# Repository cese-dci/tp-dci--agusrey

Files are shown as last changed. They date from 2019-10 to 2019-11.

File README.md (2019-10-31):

 Poncho PLC para CIAA7 - Agustín Rey

## Esquemático y PCB

Este repositorio contiene el los diagramas esquematicos y diseño de PCB del poncho PLC para la nueva placa CIAA7

### Estado Actual
Esquemático Terminado - Ruteo terminado - BOM Terminado
###
NOTA: El solapamiento de los bornes en el PCB es a propósito, porque asi pueden usarse
bornes de distinto número de polos a gusto del usuario.

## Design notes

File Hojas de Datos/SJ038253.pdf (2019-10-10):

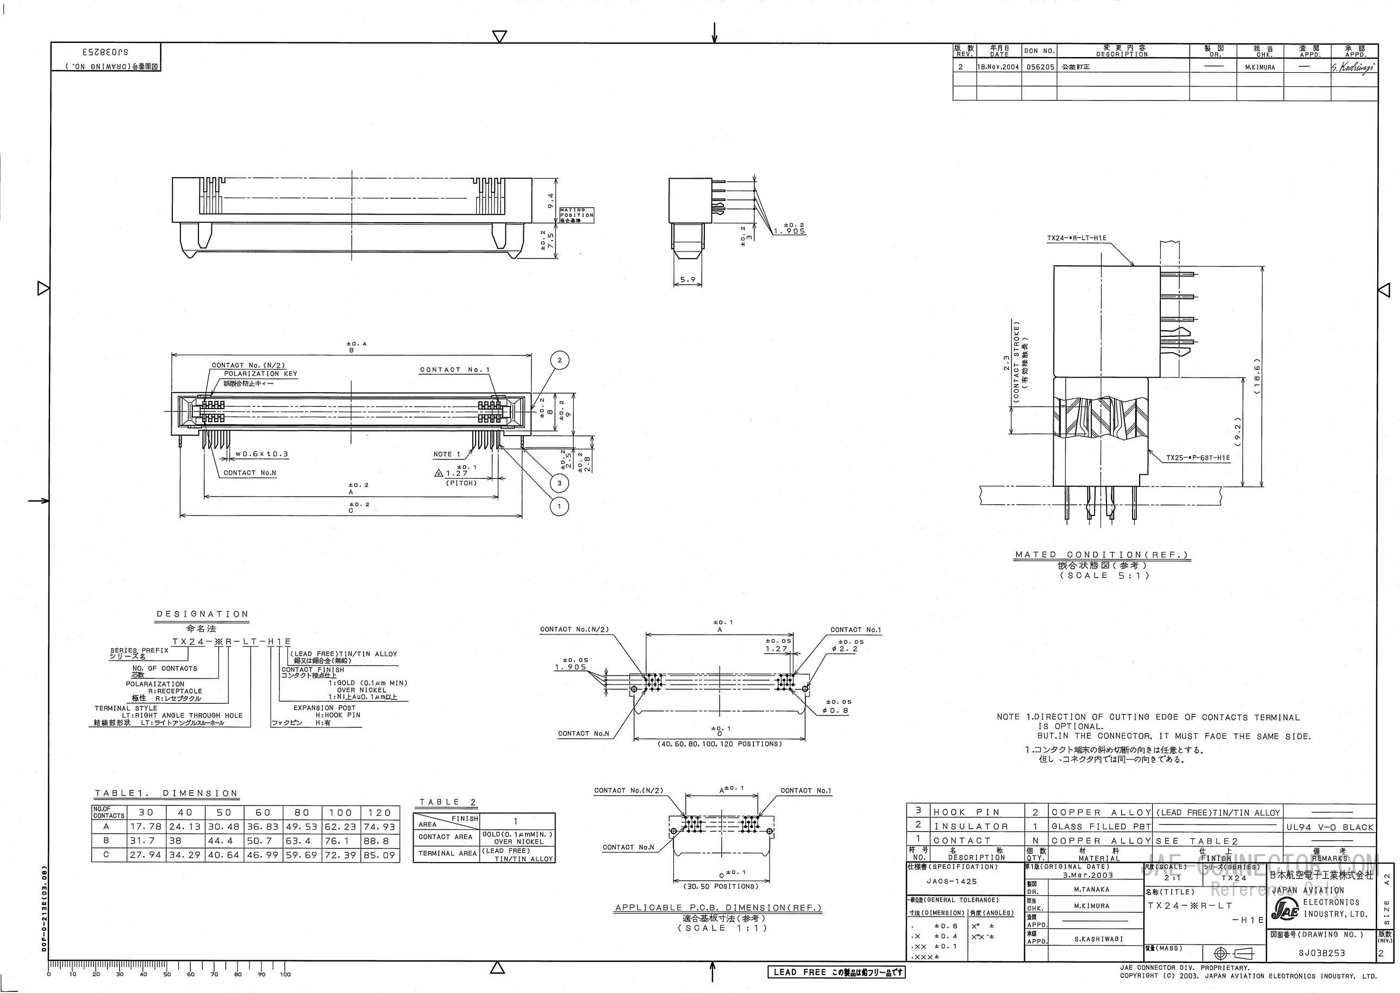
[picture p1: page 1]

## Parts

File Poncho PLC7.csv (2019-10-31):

Id | Designator | Package | Quantity | Designation | Supplier and ref
1 | J10,J7,J9 | PinSocket_2x12_P2.54mm_Vertical | 3 | Conn_02x12_Odd_Even
2 | FID3,FID2,FID1 | Fiducial_0.5mm_Mask1mm | 3 | Fiducial
3 | H8,H7,H6,H5,H1,H2,H4,H3 | MountingHole_3.2mm_M3_Pad_Via | 8 | MountingHole
4 | D8,D7,D6,D5,D4,D3,D2,D1 | LED_0805_2012Metric | 8 | LED red
5 | J18,J13 | PinSocket_2x05_P2.54mm_Vertical | 2 | Conn_02x05_Odd_Even
6 | C1,C3,C4,C9,C2 | C_0805_2012Metric | 5 | 100nF
7 | C5,C6,C7,C8 | C_1206_3216Metric | 4 | 1uF
8 | JP1,JP2,JP3,JP4 | PinHeader_1x02_P2.54mm_Vertical | 4 | Jumper
9 | Q1,Q2,Q3,Q4 | SOT-223 | 4 | FQT13N06L
10 | R1,R2,R3,R4 | R_0805_2012Metric | 4 | 100K
11 | R5,R6,R7,R8,R9,R10,R11,R12,R13,R14,R15,R16 | R_0805_2012Metric | 12 | 330
12 | R17,R19,R21,R23,R25,R27,R29,R31 | R_0805_2012Metric | 8 | 6.2K
13 | R18,R20,R22,R24,R26,R28,R30,R32 | R_0805_2012Metric | 8 | 2.7K
14 | TH1,TH2,TH3,TH4 | R_1206_3216Metric | 4 | PTS12066V100
15 | U1,U2,U3,U4 | SOT-23-5 | 4 | MCP1416
16 | U5,U6,U7,U8 | SMDIP-6_W9.53mm | 4 | VO14642AABTR
17 | U9 | QSOP-20_3.9x8.7mm_P0.635mm | 1 | SI8380P-IU
18 | J2 | TerminalBlock_WECO_120-M-311_1x03_P5.00mm_Plug-in_PCB | 1 | TB_1X3-PonchoPLC-rescue
19 | J1 | TerminalBlock_WECO_120-M-311_1x02_P5.00mm_Plug-in_PCB | 1 | TB_1X2-PonchoPLC-rescue
20 | JE3,JE2,JE1,J6,J5,J4,J3 | TerminalBlock_WECO_120-M-311_1x02_P5.00mm_Plug-in_PCB | 7 | TB_1X2
21 | JE4 | TerminalBlock_WECO_120-M-311_1x03_P5.00mm_Plug-in_PCB | 1 | TB_1X3
22 |  | OSHW-Logo2_7.3x6mm_Copper | 1
23 |  | Logo_Poncho | 1
24 | J8 | TX24-40R-LT-H1E | 1 | Conn_02x20_Counter_Clockwise

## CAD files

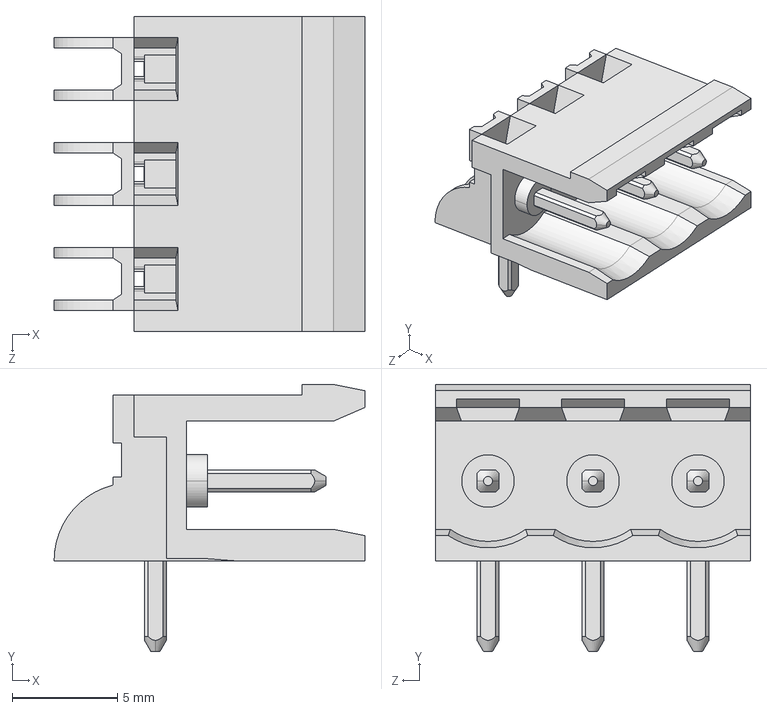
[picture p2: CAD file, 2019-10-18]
footprints/120-M-311-03.STEP
14.8 x 12.7 x 15.0 mm

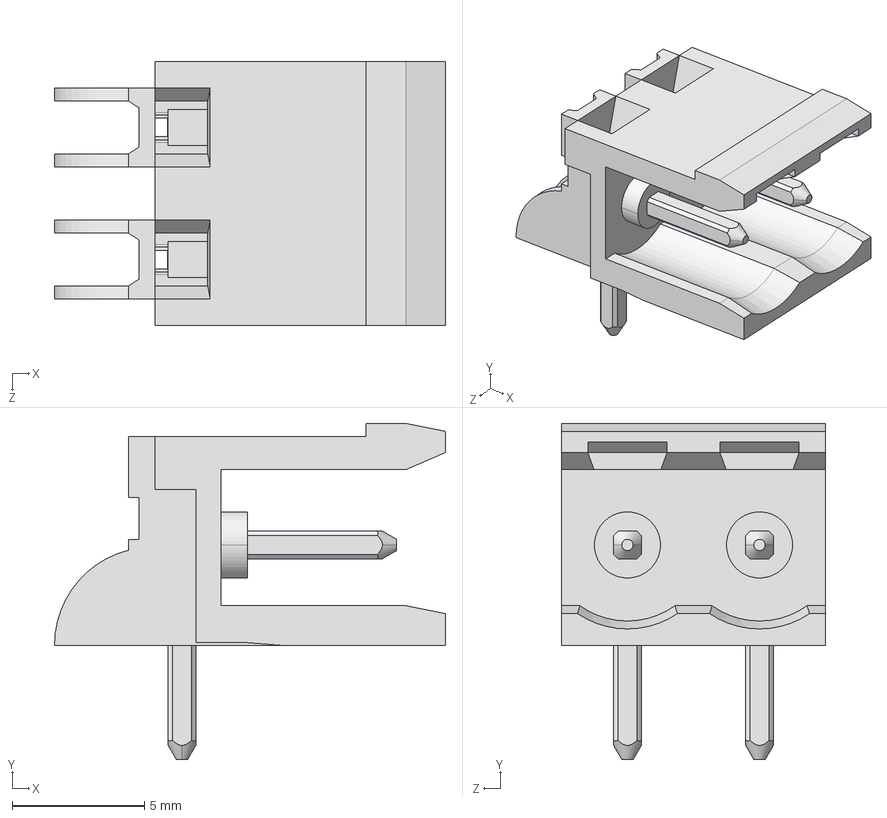
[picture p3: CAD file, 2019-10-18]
footprints/120-M-311-02.STEP
14.8 x 12.7 x 10.0 mm

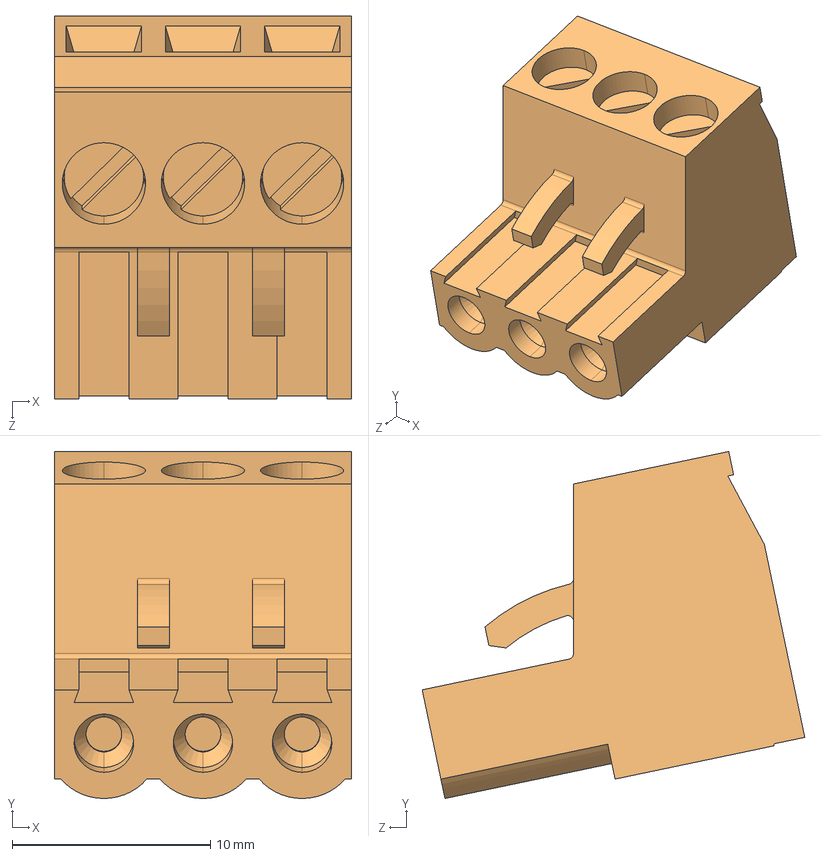
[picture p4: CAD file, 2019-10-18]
footprints/120-A-111-03.STEP
15.0 x 17.5 x 19.3 mm

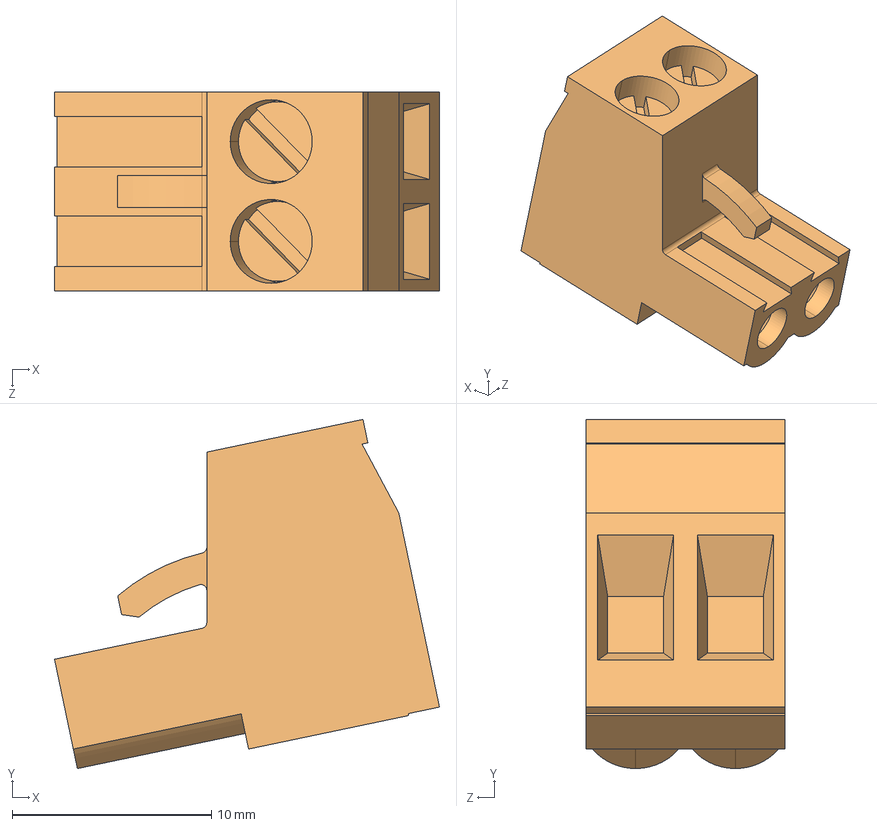
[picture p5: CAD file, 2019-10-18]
footprints/120-A-111-02.STEP
19.3 x 17.5 x 10.0 mm

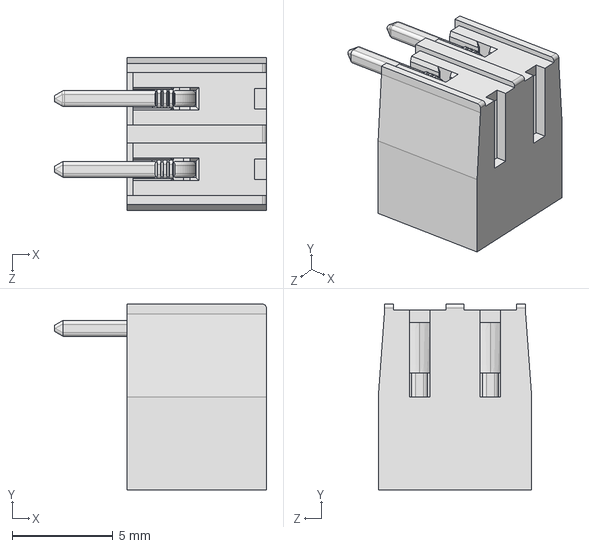
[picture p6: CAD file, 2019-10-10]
footprints/110-M-111-02.STEP
10.5 x 9.20 x 7.60 mm

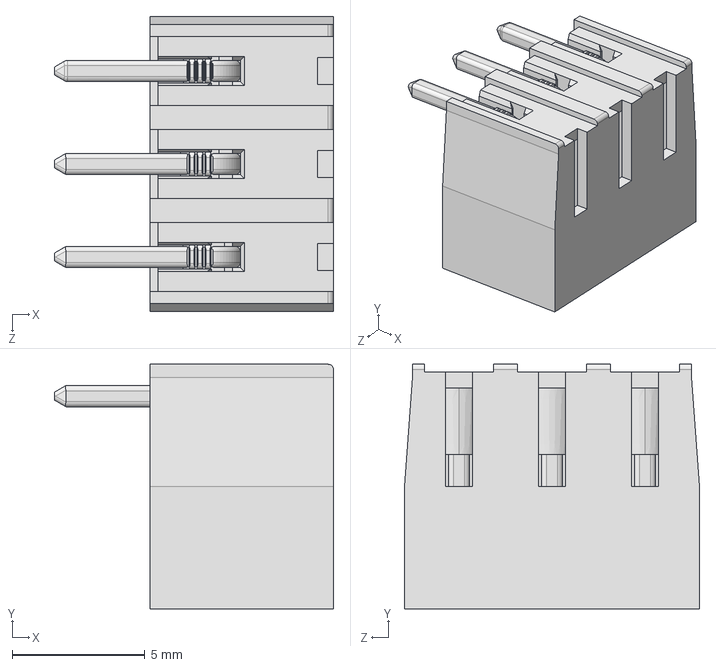
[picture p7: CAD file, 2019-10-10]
footprints/110-M-111-03.STEP
10.5 x 9.20 x 11.1 mm

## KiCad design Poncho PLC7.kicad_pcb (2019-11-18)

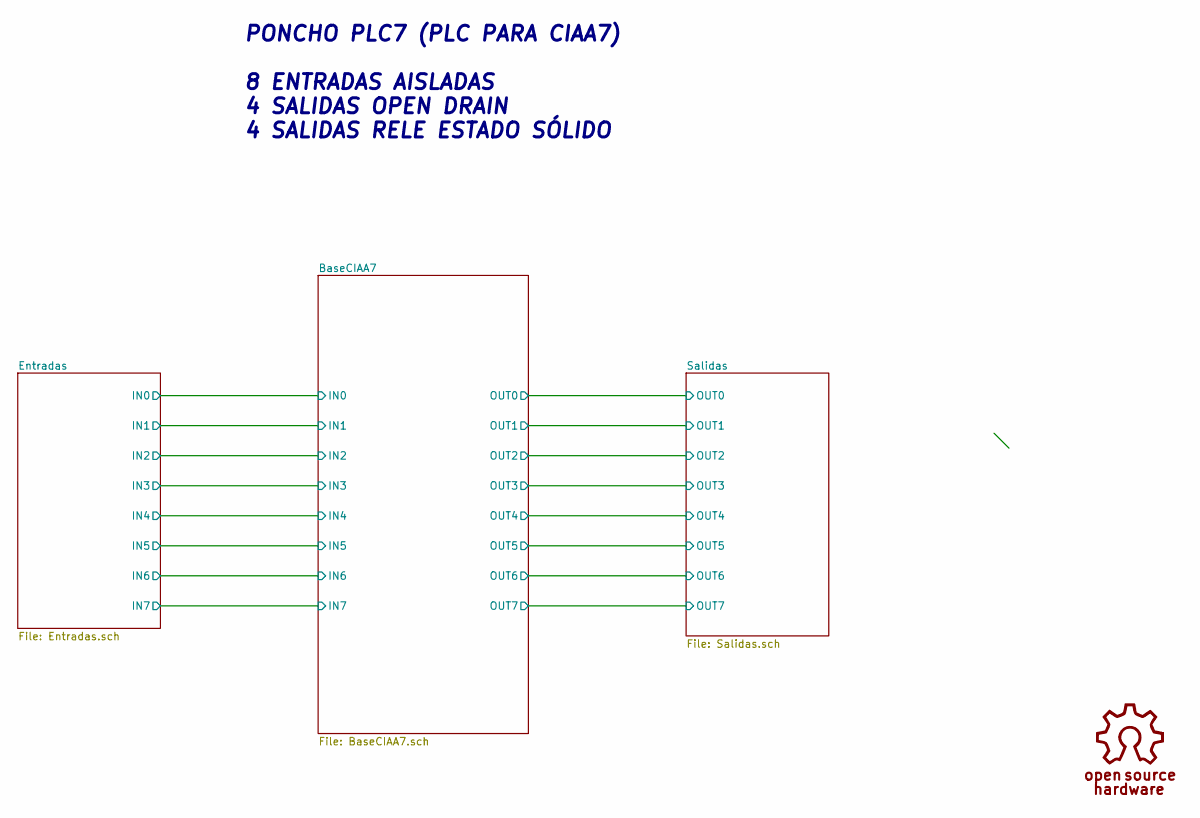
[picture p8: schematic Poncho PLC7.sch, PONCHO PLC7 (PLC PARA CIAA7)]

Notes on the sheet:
PONCHO PLC7 (PLC PARA CIAA7) 8 ENTRADAS AISLADAS 4 SALIDAS OPEN DRAIN 4 SALIDAS RELE ESTADO SÓLIDO

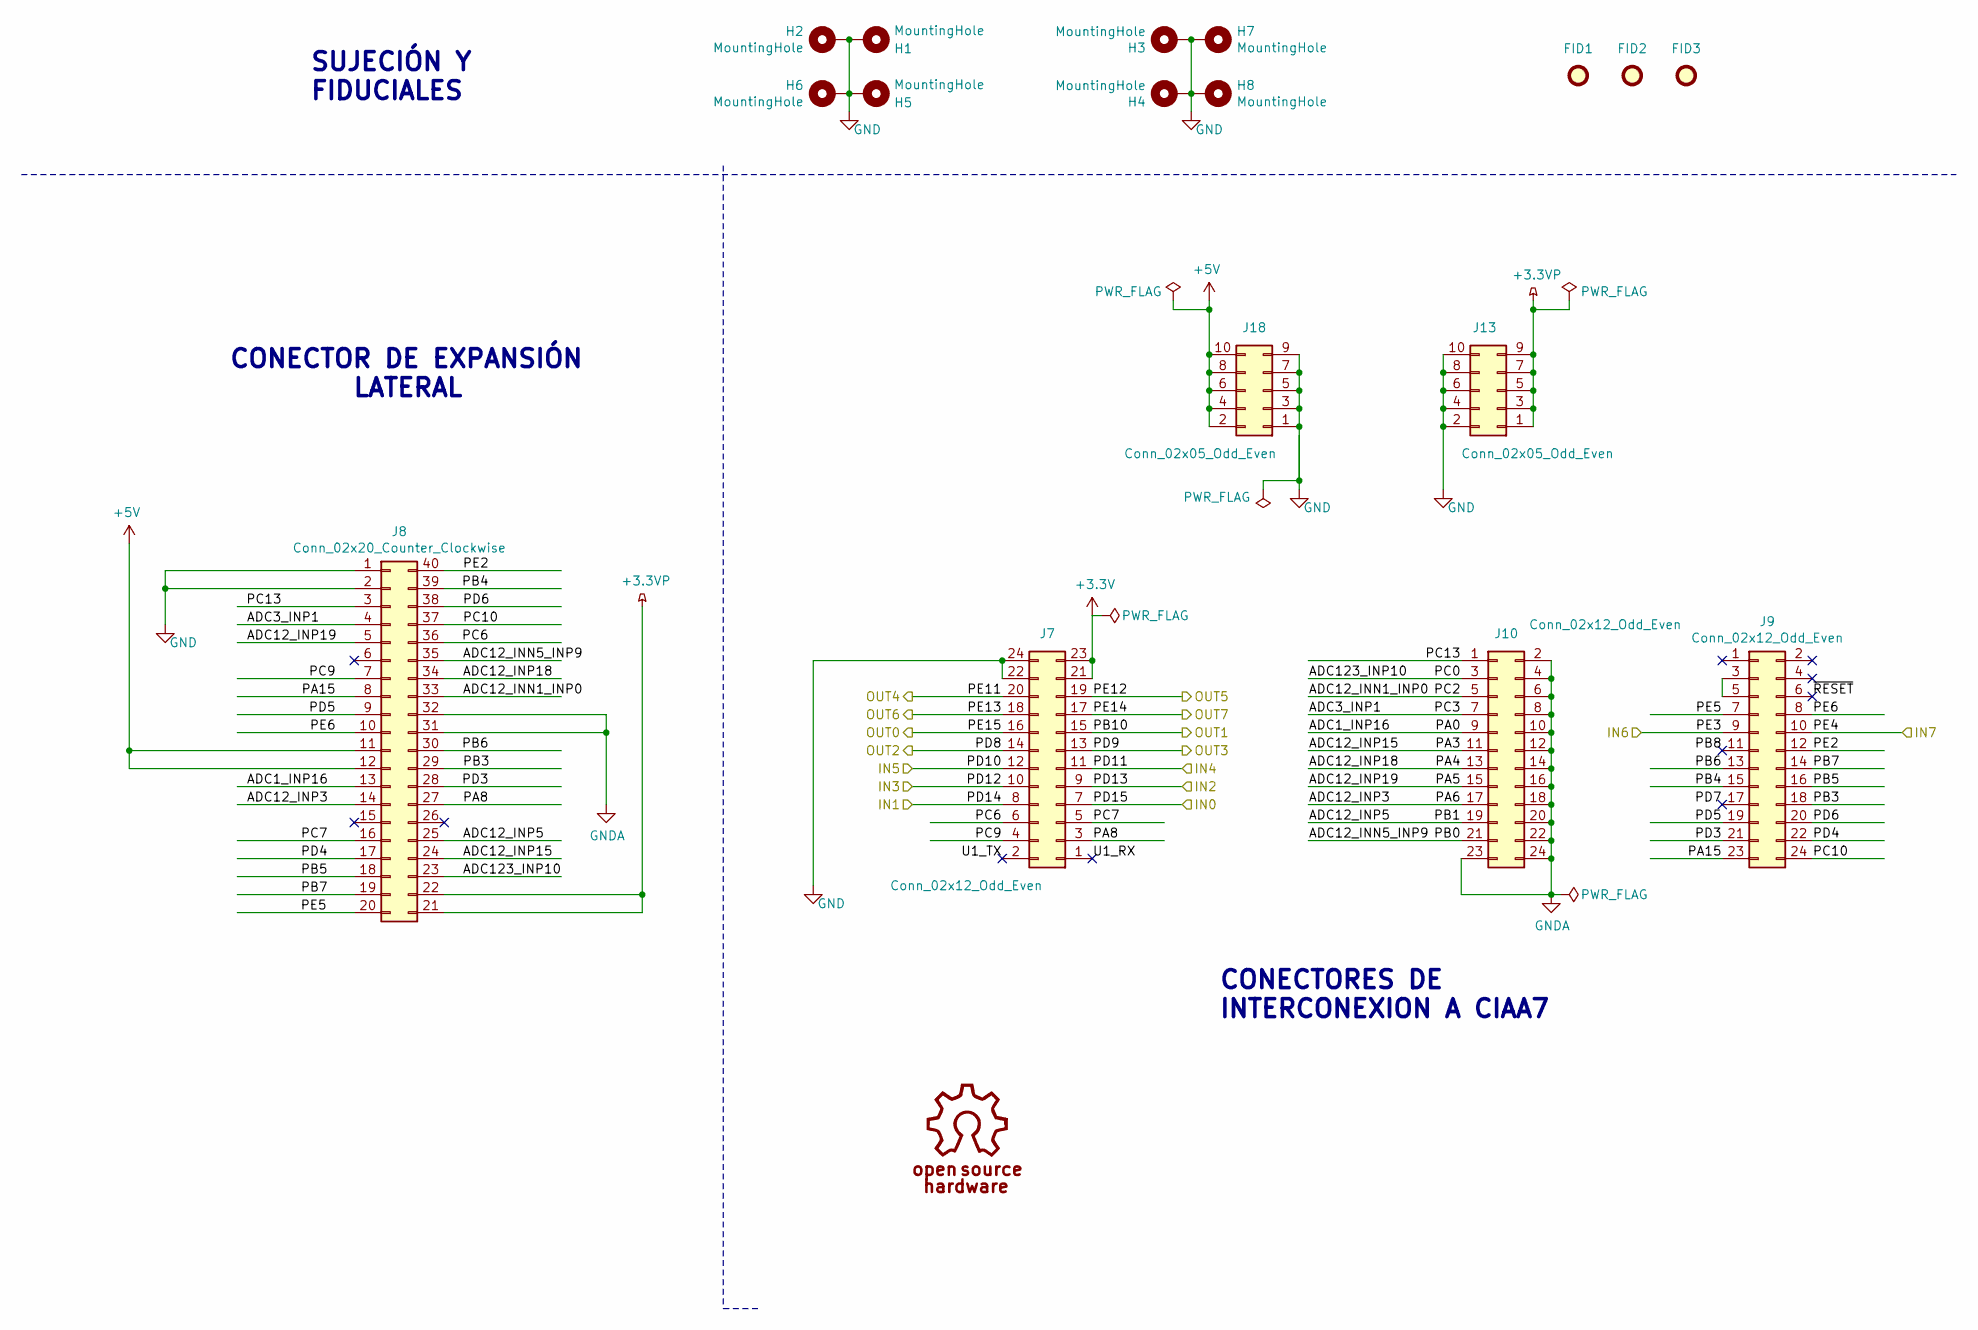
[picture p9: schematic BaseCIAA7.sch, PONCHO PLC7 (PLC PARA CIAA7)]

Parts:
FID1, FID2, FID3: Fiducial; Fiducial_0.5mm_Mask1mm
H1, H2, H3, H4, H5, H6, H7, H8: MountingHole; MountingHole_3.2mm_M3_Pad_Via
J7, J9, J10: Conn_02x12_Odd_Even; PinSocket_2x12_P2.54mm_Vertical; Digikey# 2057-PH2-12-UA-ND
J8: Conn_02x20_Counter_Clockwise; TX24-40R-LT-H1E; Digikey# 670-1386-ND
J13, J18: Conn_02x05_Odd_Even; PinSocket_2x05_P2.54mm_Vertical; Digikey# 2057-PH2-12-UA-ND

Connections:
+3.3VP: J8.21, J8.22, J13.1, J13.3, J13.5, J13.7, J13.9
+3V3: J7.21, J7.23; also elsewhere on the board
+5V: J8.11, J8.12, J18.2, J18.4, J18.6, J18.8, J18.10; also elsewhere on the board
/BaseCIAA7/ADC1_INP16: J8.13, J10.9
/BaseCIAA7/ADC3_INP1: J8.4, J10.7
/BaseCIAA7/ADC12_INN1_INP0: J8.33, J10.5
/BaseCIAA7/ADC12_INN5_INP9: J8.35, J10.21
/BaseCIAA7/ADC12_INP3: J8.14, J10.17
/BaseCIAA7/ADC12_INP5: J8.25, J10.19
/BaseCIAA7/ADC12_INP15: J8.24, J10.11
/BaseCIAA7/ADC12_INP18: J8.34, J10.13
/BaseCIAA7/ADC12_INP19: J8.5, J10.15
/BaseCIAA7/ADC123_INP10: J8.23, J10.3
/BaseCIAA7/IN0: J7.7; also elsewhere on the board
/BaseCIAA7/IN1: J7.8; also elsewhere on the board
/BaseCIAA7/IN2: J7.9; also elsewhere on the board
/BaseCIAA7/IN3: J7.10; also elsewhere on the board
/BaseCIAA7/IN4: J7.11; also elsewhere on the board
/BaseCIAA7/IN5: J7.12; also elsewhere on the board
/BaseCIAA7/IN6: J9.9; also elsewhere on the board
/BaseCIAA7/IN7: J9.10; also elsewhere on the board
/BaseCIAA7/OUT0: J7.16; also elsewhere on the board
/BaseCIAA7/OUT1: J7.15; also elsewhere on the board
/BaseCIAA7/OUT2: J7.14; also elsewhere on the board
/BaseCIAA7/OUT3: J7.13; also elsewhere on the board
/BaseCIAA7/OUT4: J7.20; also elsewhere on the board
/BaseCIAA7/OUT5: J7.19; also elsewhere on the board
/BaseCIAA7/OUT6: J7.18; also elsewhere on the board
/BaseCIAA7/OUT7: J7.17; also elsewhere on the board
/BaseCIAA7/PA8: J7.3, J8.27
/BaseCIAA7/PA15: J8.8, J9.23
/BaseCIAA7/PB3: J8.29, J9.18
/BaseCIAA7/PB4: J8.39, J9.15
/BaseCIAA7/PB5: J8.18, J9.16
/BaseCIAA7/PB6: J8.30, J9.13
/BaseCIAA7/PB7: J8.19, J9.14
/BaseCIAA7/PB8: J9.11
/BaseCIAA7/PC6: J7.6, J8.36
/BaseCIAA7/PC7: J7.5, J8.16
/BaseCIAA7/PC9: J7.4, J8.7
/BaseCIAA7/PC10: J8.37, J9.24
/BaseCIAA7/PC13: J8.3, J10.1
/BaseCIAA7/PD3: J8.28, J9.21
/BaseCIAA7/PD4: J8.17, J9.22
/BaseCIAA7/PD5: J8.9, J9.19
/BaseCIAA7/PD6: J8.38, J9.20
/BaseCIAA7/PD7: J9.17
/BaseCIAA7/PE2: J8.40, J9.12
/BaseCIAA7/PE5: J8.20, J9.7
/BaseCIAA7/PE6: J8.10, J9.8
/BaseCIAA7/U1_RX: J7.1
/BaseCIAA7/U1_TX: J7.2
/BaseCIAA7/~RESET: J9.6
GND: H1.1, H2.1, H3.1, H4.1, H5.1, H6.1, H7.1, H8.1, J7.22, J7.24, J8.1, J8.2, J13.2, J13.4, J13.6, J13.8, J13.10, J18.1, J18.3, J18.5, J18.7, J18.9; also elsewhere on the board
GNDA: J8.31, J8.32, J10.2, J10.4, J10.6, J10.8, J10.10, J10.12, J10.14, J10.16, J10.18, J10.20, J10.22, J10.23, J10.24
unnamed: J9.3, J9.5

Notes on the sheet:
CONECTORES DE INTERCONEXION A CIAA7
CONECTOR DE EXPANSIÓN LATERAL
SUJECIÓN Y FIDUCIALES

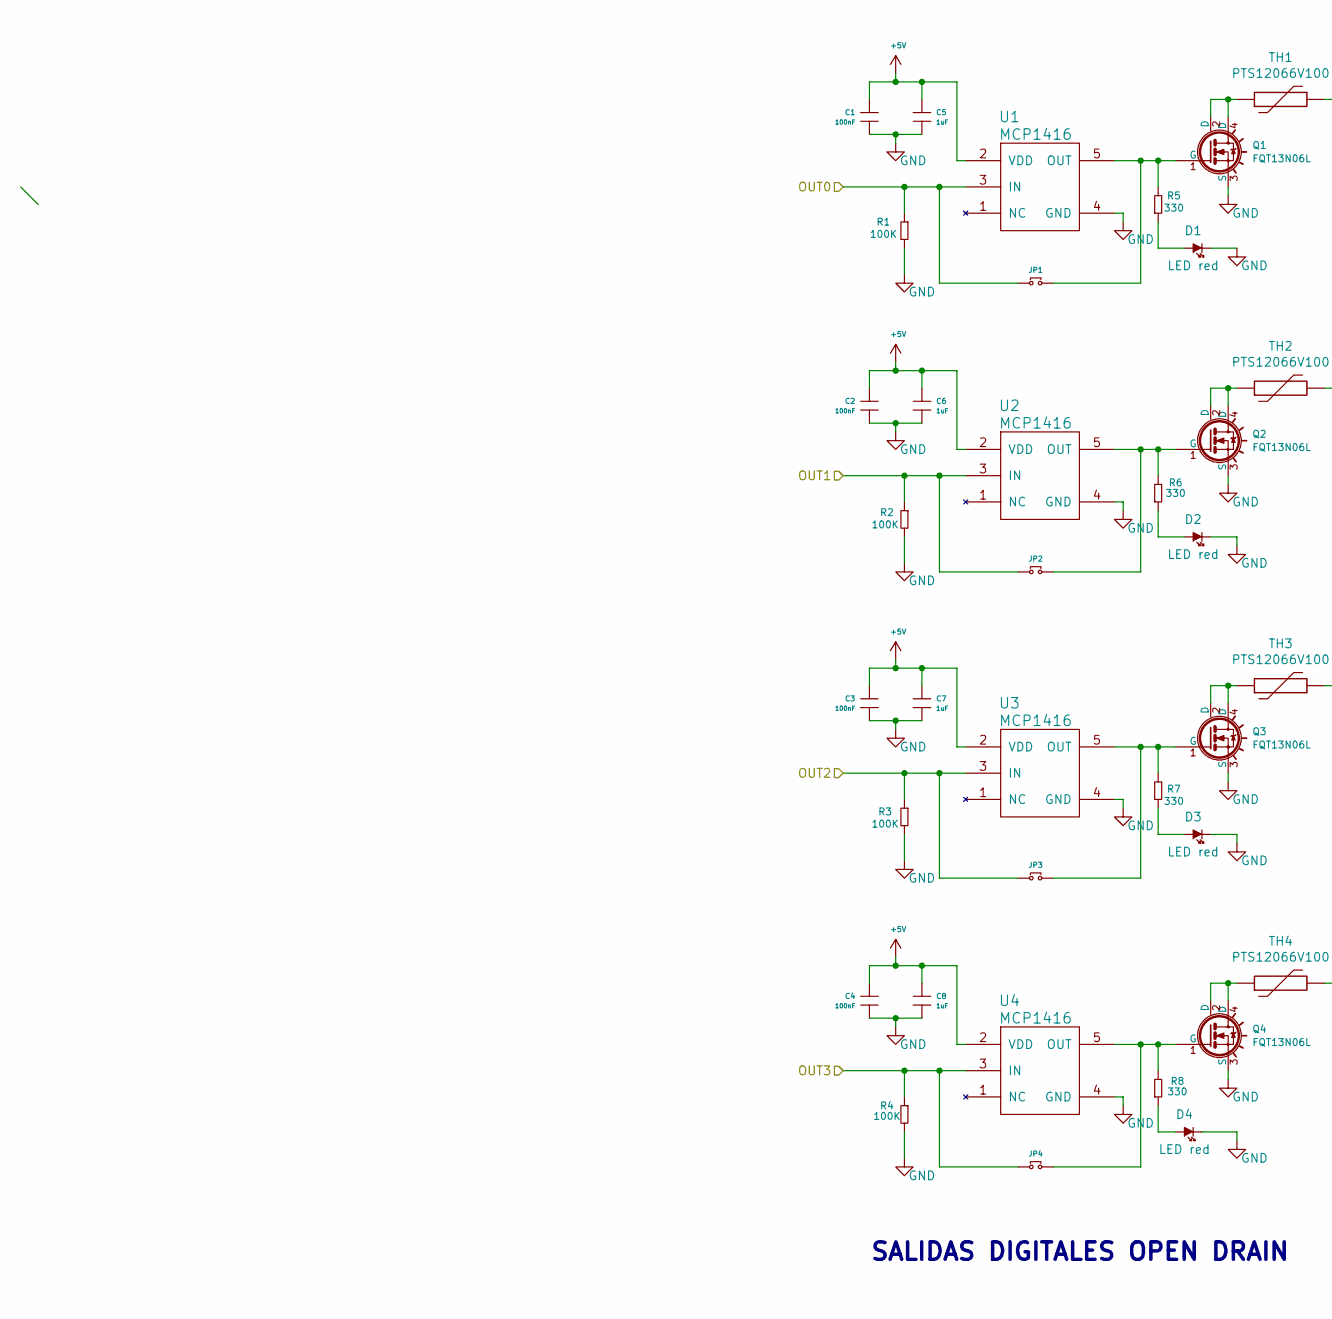
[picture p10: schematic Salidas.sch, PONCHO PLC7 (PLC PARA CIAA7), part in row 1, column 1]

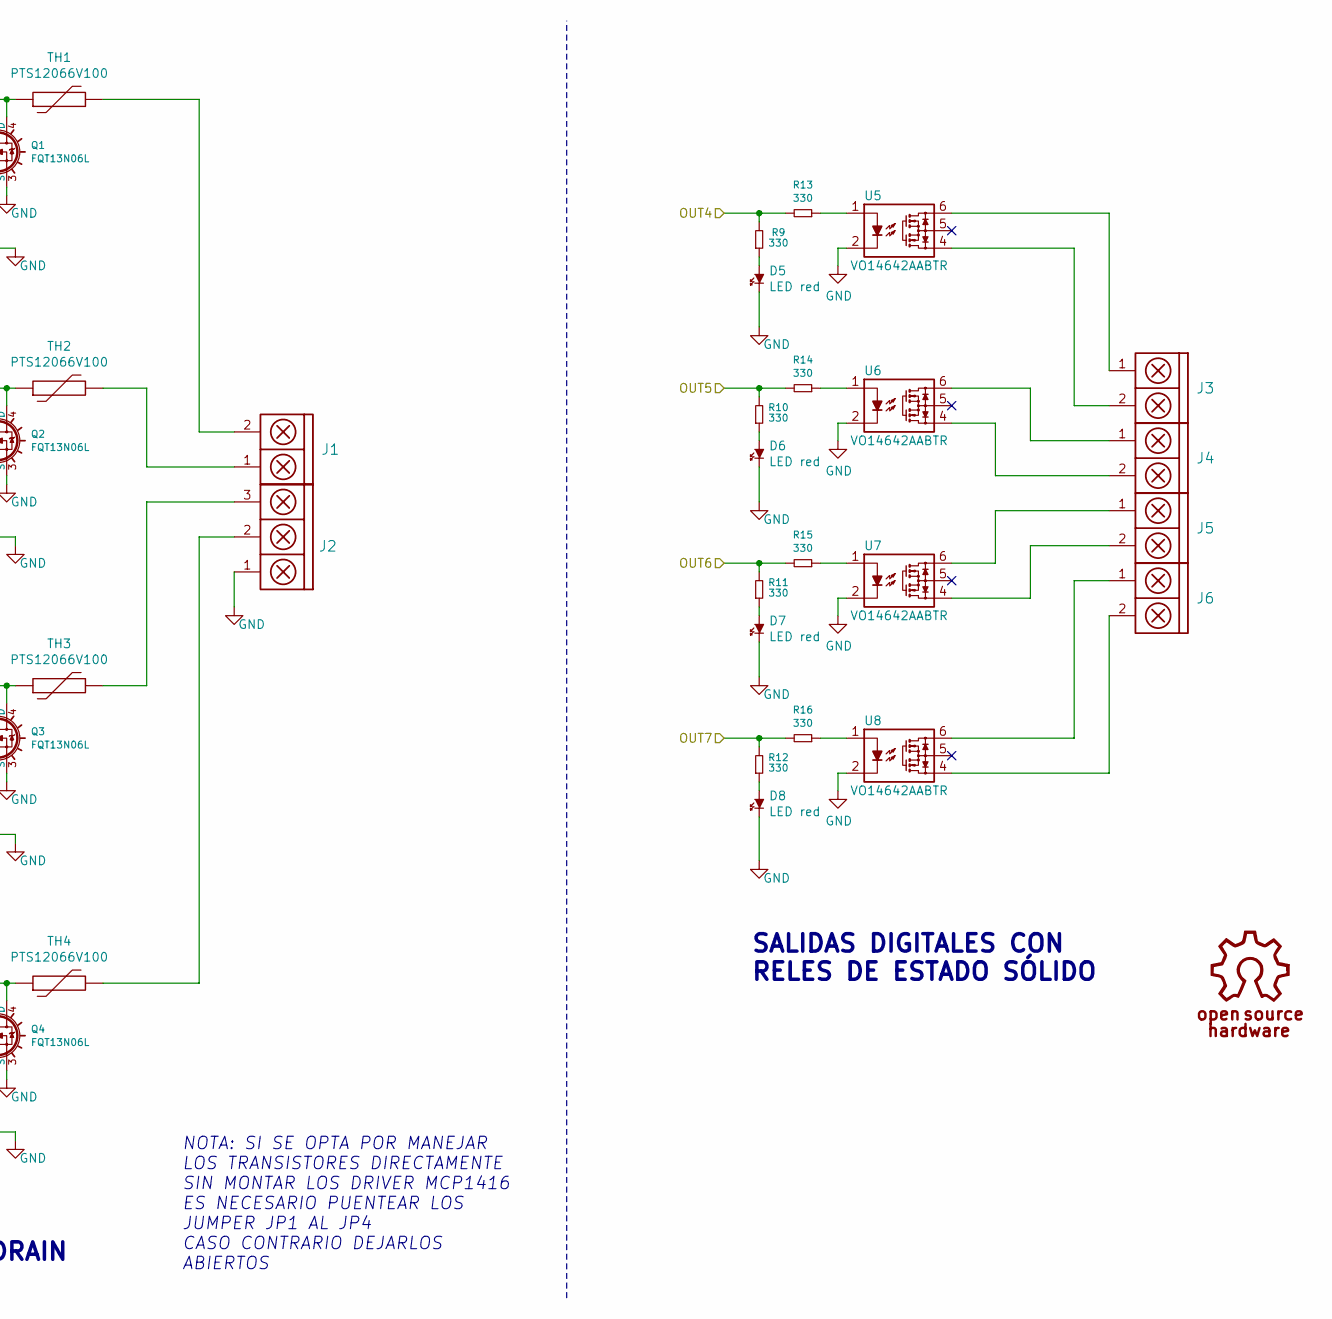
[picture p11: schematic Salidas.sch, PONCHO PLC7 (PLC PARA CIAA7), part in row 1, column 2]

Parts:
C1, C2, C3, C4: 100nF; C_0805_2012Metric; Digikey# CL31B104KBCNNNL-ND
C5, C6, C7, C8: 1uF; C_1206_3216Metric; Digikey# 1276-1007-2-ND
D1, D2, D3, D4, D5, D6, D7, D8: LED red; LED_0805_2012Metric; Digikey# 1080-1583-2-ND
J1: TB_1X2-PonchoPLC-rescue; TerminalBlock_WECO_120-M-311_1x02_P5.00mm_Plug-in_PCB; Digikey# A98062-ND
J2: TB_1X3-PonchoPLC-rescue; TerminalBlock_WECO_120-M-311_1x03_P5.00mm_Plug-in_PCB; Digikey# A98063-ND
J3, J4, J5, J6: TB_1X3-PonchoPLC-rescue; TerminalBlock_WECO_120-M-311_1x02_P5.00mm_Plug-in_PCB; Digikey# A98063-ND
JP1, JP2, JP3, JP4: Jumper; PinHeader_1x02_P2.54mm_Vertical; Digikey# 2057-PH2-12-UA-ND
Q1, Q2, Q3, Q4: FQT13N06L; SOT-223; Digikey# FQT13N06LTFTR-ND
R1, R2, R3, R4: 100K; R_0805_2012Metric; Digikey# CR0805-JW-104ELFTR-ND
R5, R6, R7, R8, R9, R10, R11, R12, R13, R14, R15, R16: 330; R_0805_2012Metric; Digikey# CR0805-JW-331ELFTR-ND
TH1, TH2, TH3, TH4: PTS12066V100; R_1206_3216Metric; Digikey# 283-3142-1-ND
U1, U2, U3, U4: MCP1416; SOT-23-5; Digikey# MCP1416T-E/OTTR-ND
U5, U6, U7, U8: VO14642AABTR; SMDIP-6_W9.53mm; Digikey# VO14642AABCT-ND

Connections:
+5V: C1.2 (B), C2.2 (B), C3.2 (B), C4.2 (B), C5.2 (B), C6.2 (B), C7.2 (B), C8.2 (B), U1.2 (VDD), U2.2 (VDD), U3.2 (VDD), U4.2 (VDD); also elsewhere on the board
/BaseCIAA7/OUT0: JP1.1 (A), R1.1, U1.3 (IN); also elsewhere on the board
/BaseCIAA7/OUT1: JP2.1 (A), R2.1, U2.3 (IN); also elsewhere on the board
/BaseCIAA7/OUT2: JP3.1 (A), R3.1, U3.3 (IN); also elsewhere on the board
/BaseCIAA7/OUT3: JP4.1 (A), R4.1, U4.3 (IN); also elsewhere on the board
/BaseCIAA7/OUT4: R9.2, R13.2; also elsewhere on the board
/BaseCIAA7/OUT5: R10.2, R14.2; also elsewhere on the board
/BaseCIAA7/OUT6: R11.2, R15.2; also elsewhere on the board
/BaseCIAA7/OUT7: R12.2, R16.2; also elsewhere on the board
GND: C1.1 (A), C2.1 (A), C3.1 (A), C4.1 (A), C5.1 (A), C6.1 (A), C7.1 (A), C8.1 (A), D1.2 (K), D2.2 (K), D3.2 (K), D4.2 (K), D5.2 (K), D6.2 (K), D7.2 (K), D8.2 (K), J2.1, Q1.3 (S), Q2.3 (S), Q3.3 (S), Q4.3 (S), R1.2, R2.2, R3.2, R4.2, U1.4 (GND), U2.4 (GND), U3.4 (GND), U4.4 (GND), U5.2, U6.2, U7.2, U8.2; also elsewhere on the board
unnamed: D1.1 (A), R5.1
unnamed: D2.1 (A), R6.1
unnamed: D3.1 (A), R7.1
unnamed: D4.1 (A), R8.1
unnamed: D5.1 (A), R9.1
unnamed: D6.1 (A), R10.1
unnamed: D7.1 (A), R11.1
unnamed: D8.1 (A), R12.1
unnamed: J1.1, TH2.2
unnamed: J1.2, TH1.2
unnamed: J2.2, TH4.2
unnamed: J2.3, TH3.2
unnamed: J3.1, U5.6
unnamed: J3.2, U5.4
unnamed: J4.1, U6.6
unnamed: J4.2, U6.4
unnamed: J5.1, U7.6
unnamed: J5.2, U7.4
unnamed: J6.1, U8.6
unnamed: J6.2, U8.4
unnamed: JP1.2 (B), Q1.1 (G), R5.2, U1.5 (OUT)
unnamed: JP2.2 (B), Q2.1 (G), R6.2, U2.5 (OUT)
unnamed: JP3.2 (B), Q3.1 (G), R7.2, U3.5 (OUT)
unnamed: JP4.2 (B), Q4.1 (G), R8.2, U4.5 (OUT)
unnamed: Q1.2 (D), Q1.4 (D), TH1.1
unnamed: Q2.2 (D), Q2.4 (D), TH2.1
unnamed: Q3.2 (D), Q3.4 (D), TH3.1
unnamed: Q4.2 (D), Q4.4 (D), TH4.1
unnamed: R13.1, U5.1
unnamed: R14.1, U6.1
unnamed: R15.1, U7.1
unnamed: R16.1, U8.1

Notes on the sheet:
SALIDAS DIGITALES CON RELES DE ESTADO SÓLIDO
SALIDAS DIGITALES OPEN DRAIN
NOTA: SI SE OPTA POR MANEJAR LOS TRANSISTORES DIRECTAMENTE SIN MONTAR LOS DRIVER MCP1416 ES NECESARIO PUENTEAR LOS JUMPER JP1 AL JP4 CASO CONTRARIO DEJARLOS ABIERTOS

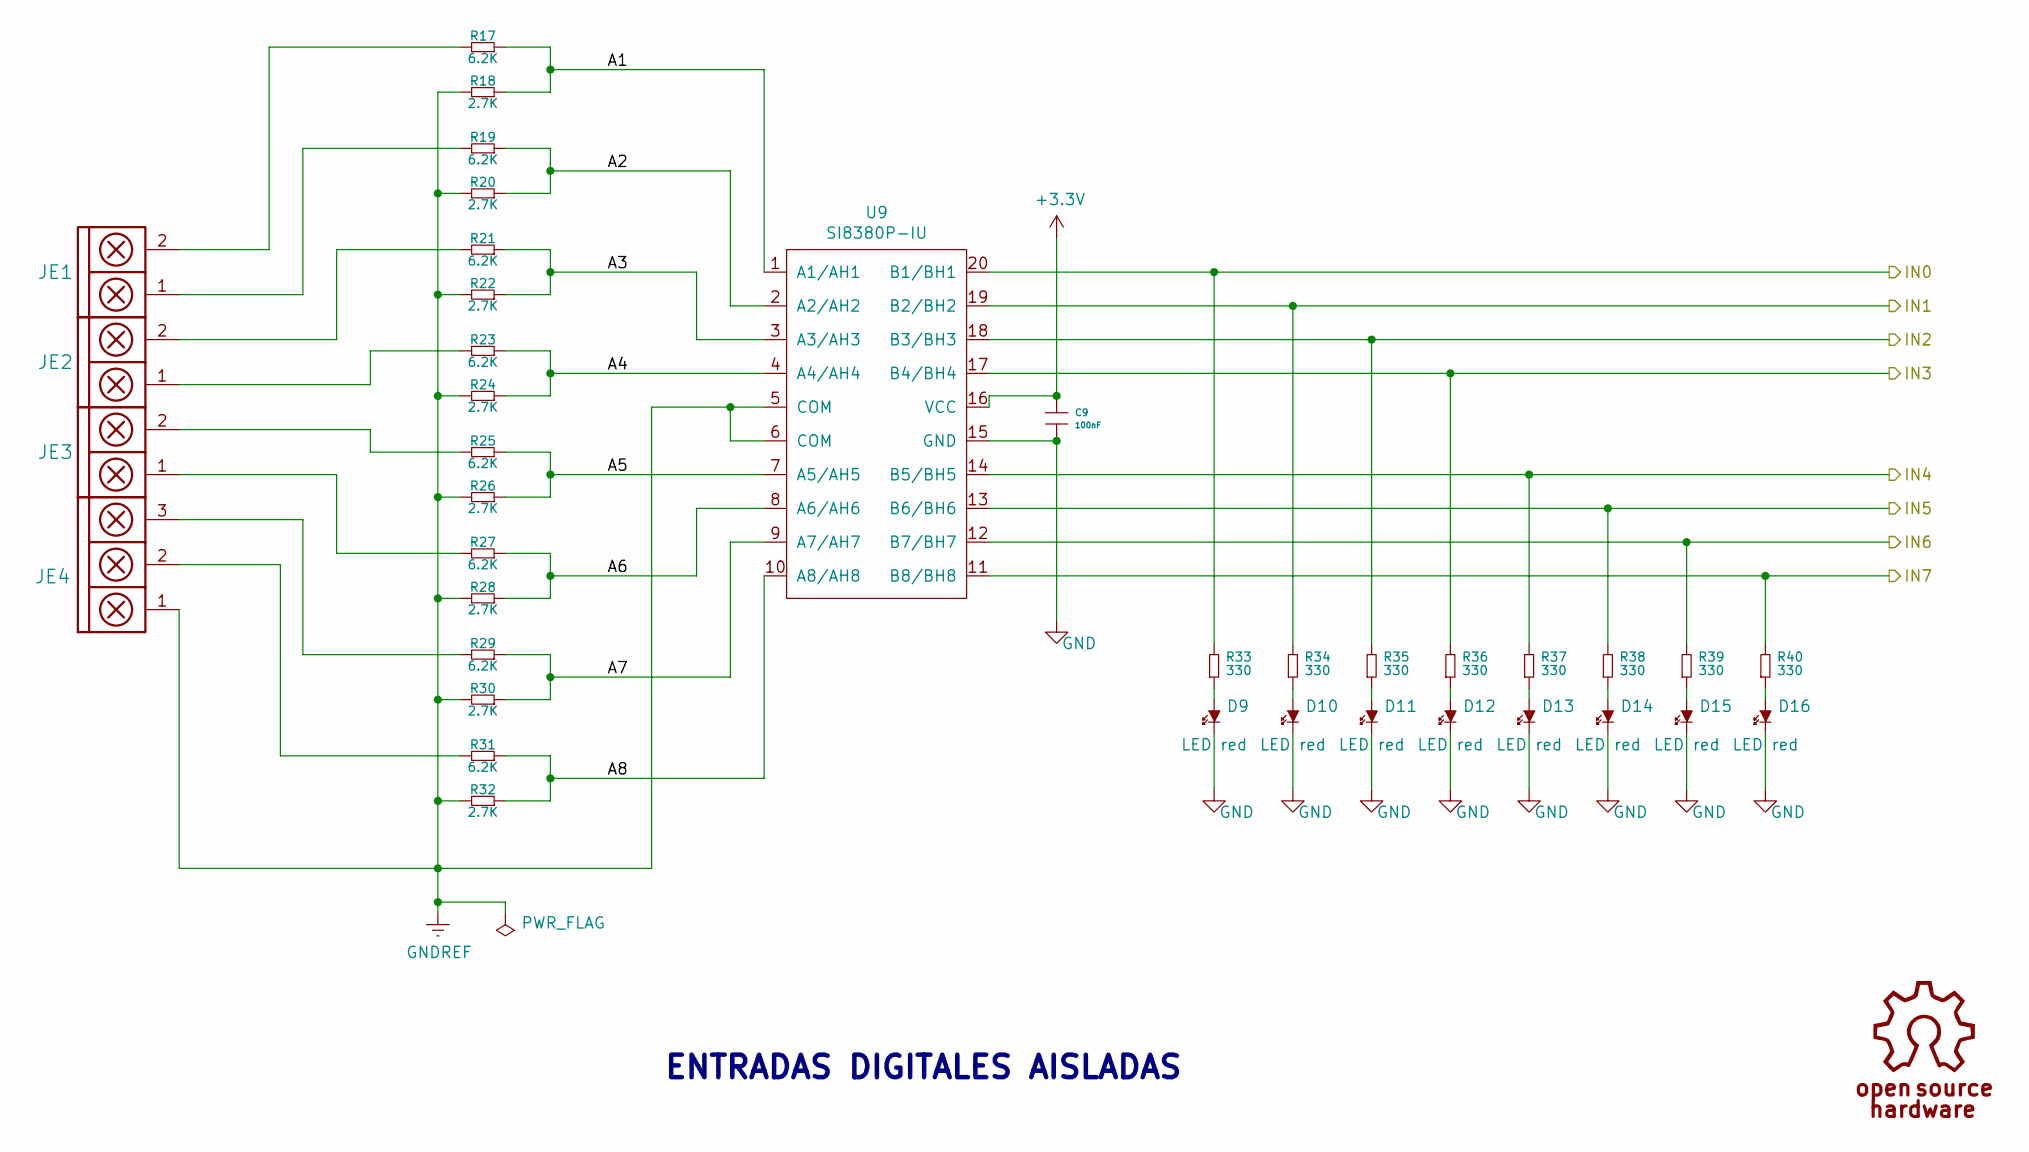
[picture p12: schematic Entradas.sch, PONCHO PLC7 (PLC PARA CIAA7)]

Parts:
C9: 100nF; C_0805_2012Metric; Digikey# CL31B104KBCNNNL-ND
D9, D10, D11, D12, D13, D14, D15, D16: LED red; LED_0805_2012Metric; Digikey# 1080-1583-2-ND
JE1, JE2, JE3: TB_1X2-PonchoPLC-rescue; TerminalBlock_WECO_120-M-311_1x02_P5.00mm_Plug-in_PCB; Digikey# A98062-ND
JE4: TB_1X3-PonchoPLC-rescue; TerminalBlock_WECO_120-M-311_1x03_P5.00mm_Plug-in_PCB; Digikey# A98063-ND
R17, R19, R21, R23, R25, R27, R29, R31: 6.2K; R_0805_2012Metric; Digikey# CR0805-JW-622ELFTR-ND
R18, R20, R22, R24, R26, R28, R30, R32: 2.7K; R_0805_2012Metric; Digikey# CR0805-JW-272ELFTR-ND
R33, R34, R35, R36, R37, R38, R39, R40: 330; R_0805_2012Metric; Digikey# CR0805-JW-331ELFTR-ND
U9: SI8380P-IU; QSOP-20_3.9x8.7mm_P0.635mm; Digikey# 336-3618-5-ND

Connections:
+3V3: C9.2 (B), U9.16 (VCC); also elsewhere on the board
/BaseCIAA7/IN0: R33.2, U9.20 (B1/BH1); also elsewhere on the board
/BaseCIAA7/IN1: R34.2, U9.19 (B2/BH2); also elsewhere on the board
/BaseCIAA7/IN2: R35.2, U9.18 (B3/BH3); also elsewhere on the board
/BaseCIAA7/IN3: R36.2, U9.17 (B4/BH4); also elsewhere on the board
/BaseCIAA7/IN4: R37.2, U9.14 (B5/BH5); also elsewhere on the board
/BaseCIAA7/IN5: R38.2, U9.13 (B6/BH6); also elsewhere on the board
/BaseCIAA7/IN6: R39.2, U9.12 (B7/BH7); also elsewhere on the board
/BaseCIAA7/IN7: R40.2, U9.11 (B8/BH8); also elsewhere on the board
/Entradas/A1: R17.1, R18.1, U9.1 (A1/AH1)
/Entradas/A2: R19.1, R20.1, U9.2 (A2/AH2)
/Entradas/A3: R21.1, R22.1, U9.3 (A3/AH3)
/Entradas/A4: R23.1, R24.1, U9.4 (A4/AH4)
/Entradas/A5: R25.1, R26.1, U9.7 (A5/AH5)
/Entradas/A6: R27.1, R28.1, U9.8 (A6/AH6)
/Entradas/A7: R29.1, R30.1, U9.9 (A7/AH7)
/Entradas/A8: R31.1, R32.1, U9.10 (A8/AH8)
GND: C9.1 (A), D9.2 (K), D10.2 (K), D11.2 (K), D12.2 (K), D13.2 (K), D14.2 (K), D15.2 (K), D16.2 (K), U9.15 (GND); also elsewhere on the board
GNDREF: JE4.1, R18.2, R20.2, R22.2, R24.2, R26.2, R28.2, R30.2, R32.2, U9.5 (COM), U9.6 (COM)
unnamed: D9.1 (A), R33.1
unnamed: D10.1 (A), R34.1
unnamed: D11.1 (A), R35.1
unnamed: D12.1 (A), R36.1
unnamed: D13.1 (A), R37.1
unnamed: D14.1 (A), R38.1
unnamed: D15.1 (A), R39.1
unnamed: D16.1 (A), R40.1
unnamed: JE1.1, R19.2
unnamed: JE1.2, R17.2
unnamed: JE2.1, R23.2
unnamed: JE2.2, R21.2
unnamed: JE3.1, R27.2
unnamed: JE3.2, R25.2
unnamed: JE4.2, R31.2
unnamed: JE4.3, R29.2

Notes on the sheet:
ENTRADAS DIGITALES AISLADAS

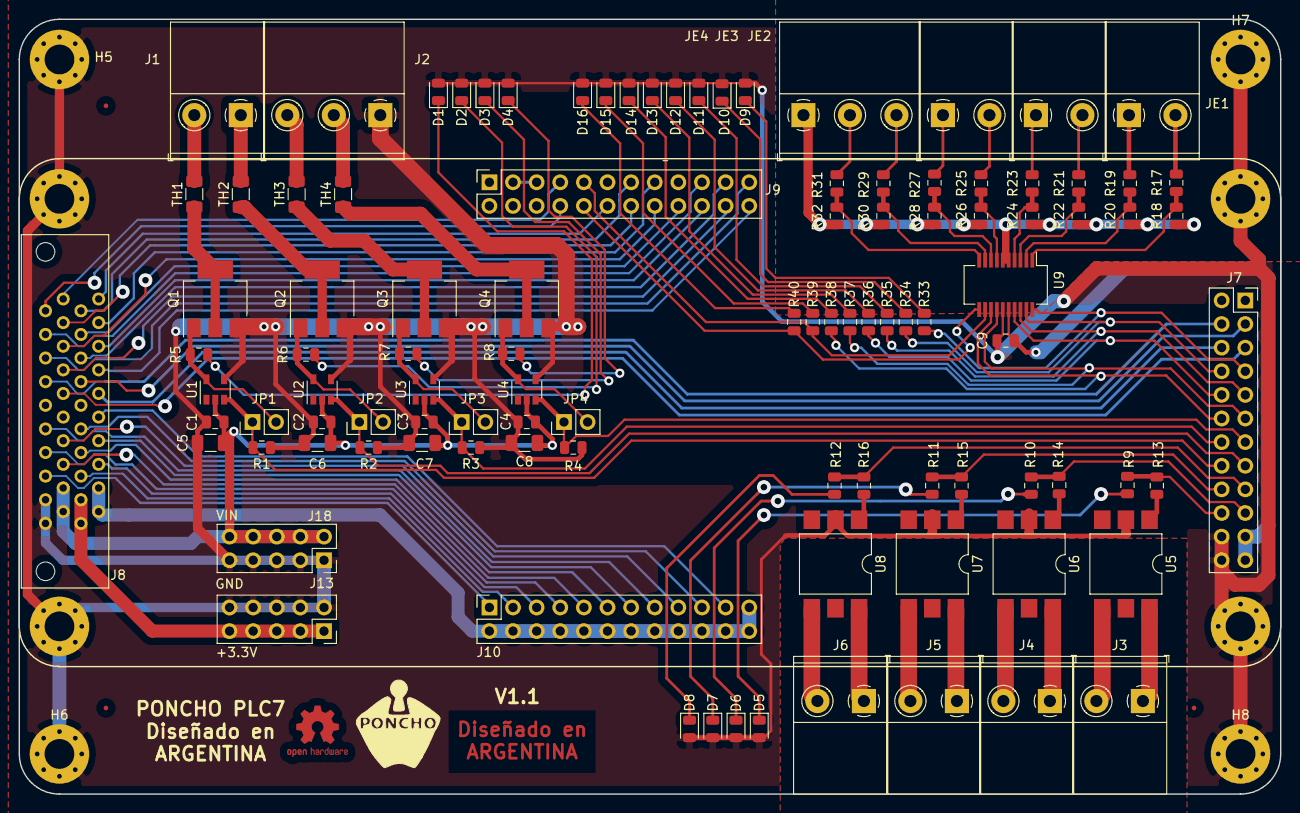
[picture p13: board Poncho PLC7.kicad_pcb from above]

Board: 2 copper layers, 135.6 x 83.3 mm, 115 parts (0 on the bottom side), 108 nets.

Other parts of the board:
 : OSHW-Logo2_7.3x6mm_Copper
 #2: Logo_Poncho

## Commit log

2019-10-01 mi primer commit
    [BaseCIAA7.sch, Entradas.sch, Poncho PLC7.kicad_pcb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]
2019-10-10 version 2
    [110-M-111-02.STEP, 110-M-111-03.STEP, K3D-TX25-40P-LT-N1E-R1 JAE Connector Division Proprietary.STEP]
2019-10-10 version 3
    [BaseCIAA7.sch, Entradas.sch, Expansion.sch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]
2019-10-18 Version 4
    [120-A-111-02.STEP, 120-A-111-03.STEP, 120-M-311-02.STEP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]
2019-10-23 Ruteo Parcial-Replanteo Esquematico pafa favorecer ruteo
    [BaseCIAA7.sch, Entradas.sch, Poncho PLC7.kicad_pcb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]
2019-10-23 Ruteo Parcial-Replanteo Esquematico pafa favorecer ruteo 2
    [Expansion.sch, K3D-TX25-40P-LT-N1E-R1 JAE Connector Division Proprietary.STEP, tmp.sch]
2019-10-23 Ruteo Parcial-Replanteo Esquematico pafa favorecer ruteo 3
    [BaseCIAA7.sch, Entradas.sch, K3D-TX25-40P-LT-N1E-R1 JAE Connector Division Proprietary.STEP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]
2019-10-24 Ruteo Parcial-Replanteo Esquematico pafa favorecer ruteo v4
    [BaseCIAA7.sch, Poncho PLC7.kicad_pcb]
2019-10-25 Ruteo Casi terminado (faltan planos de masa)
    [BaseCIAA7.sch, Entradas.sch, Poncho PLC7.kicad_pcb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]
2019-10-30 Esq y Ruteo 100% - falta Bom
2019-10-31 Esq + PCB + Bom terminados
    [BaseCIAA7.sch, Entradas.sch, Poncho PLC7.csv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]
2019-11-18 Agregado Leds Entradas
    [Entradas.sch, Poncho PLC7.kicad_pcb, Salidas.sch]
